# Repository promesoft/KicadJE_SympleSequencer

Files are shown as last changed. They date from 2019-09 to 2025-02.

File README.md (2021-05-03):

# KicadJE_SympleSequencer
Designed to fit the faceplate of a Hexinverter SympleSeq E2 faceplate from Re:Synthesis

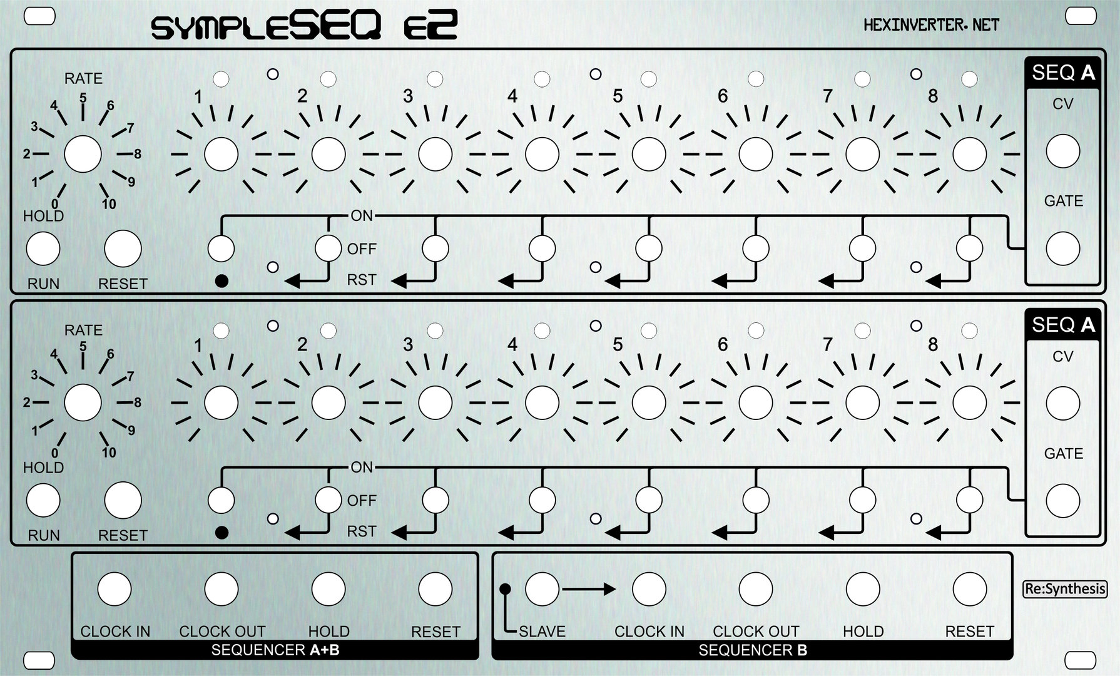
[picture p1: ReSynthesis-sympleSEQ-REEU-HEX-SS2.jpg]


# Purpose
1 - Match Hexinverter sch with Resynthesis panel

# Rev 2

# Status - Mouted - testing
## Initial 
| Stage  | Detail | Status |
| --- | --- | --- |
| create material  | sch/pcb | OK  |
| | gerber | OK |
| production  | | ok |
|  | produced | ok |
|  | delivered | ok |

## Preliminary validation
| Test  | Detail | Status |
| --- | --- | --- |
| Initial Inspection | clock board| ok |
| Initial Inspection | control board | ok  |
| Initial Technical Test |  | 100n capacitors in series w output is replaced w 2k |
| Initial Product Test |  | 100n C101 capacitor parallel w 150k |
| Initial Product Test |  | ongoing |

## Secondary validation
| Test  | Detail | Status |
| --- | --- |--- |
| Product Test | CV |  |
| Product Test | Gate | |
| Product Test | Clock internal |  |
| Product Test | Clock in |  |
| Product Test | Clock out |  |
| Product Test | Reset In/Button |  |
| Product Test | Hold In/Button |  |
| Quality | CV |  |
| Quality | Gate |  |
| Long Term Product Test |  | Good |
| Power Draw |  | 

## Errata
### Errata - clock
#### Series capacitors not working with reset (overloads CD4017)
 - replace w resistors (2k and 9k1 tested and working fine)
#### Hold not working 
 - Either swap R206 100k pullup with 22k-47k and R212 10k with 100k or tie hold to +12v works
### Errata - control
#### 

## Issues and Notes
### Clock
1 - diodes for hold input  
2 - diodes for reset input  
3 - Gate AND Clock for gate output to reset between gates - consider making a phase adjust for shorter/longer gates  
4 - OPEN resistor from Internal CLK to 4017 clock in (for use with Sequencer A that does not take slave clk input)
### Control
1 - switches still reversed  
2 - diode missing for reset  
3 - consider moving resistors from clk module to control as there is plenty of room  

# Schematics
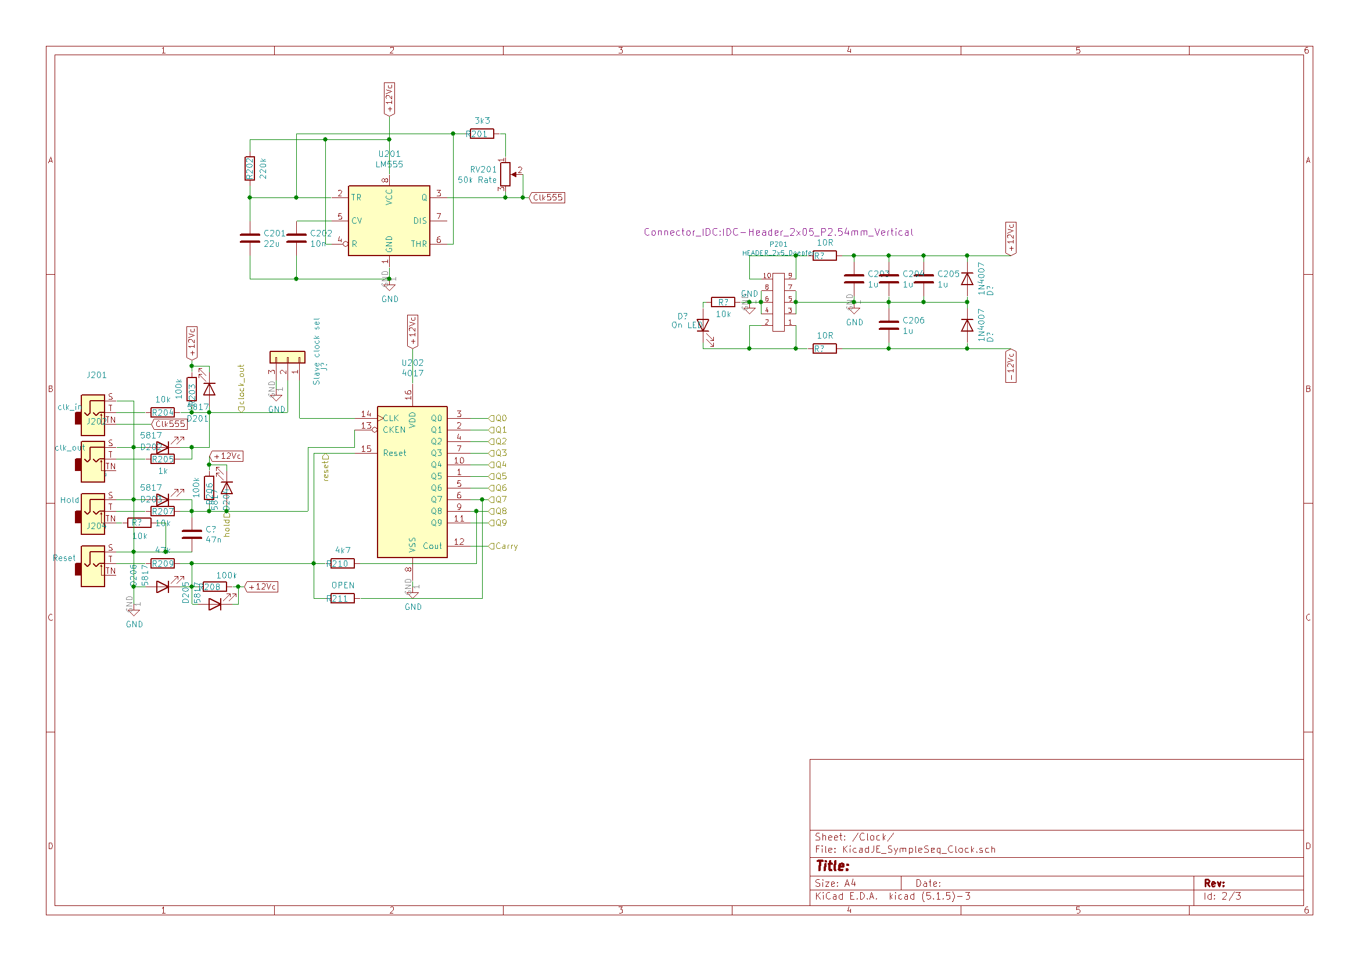
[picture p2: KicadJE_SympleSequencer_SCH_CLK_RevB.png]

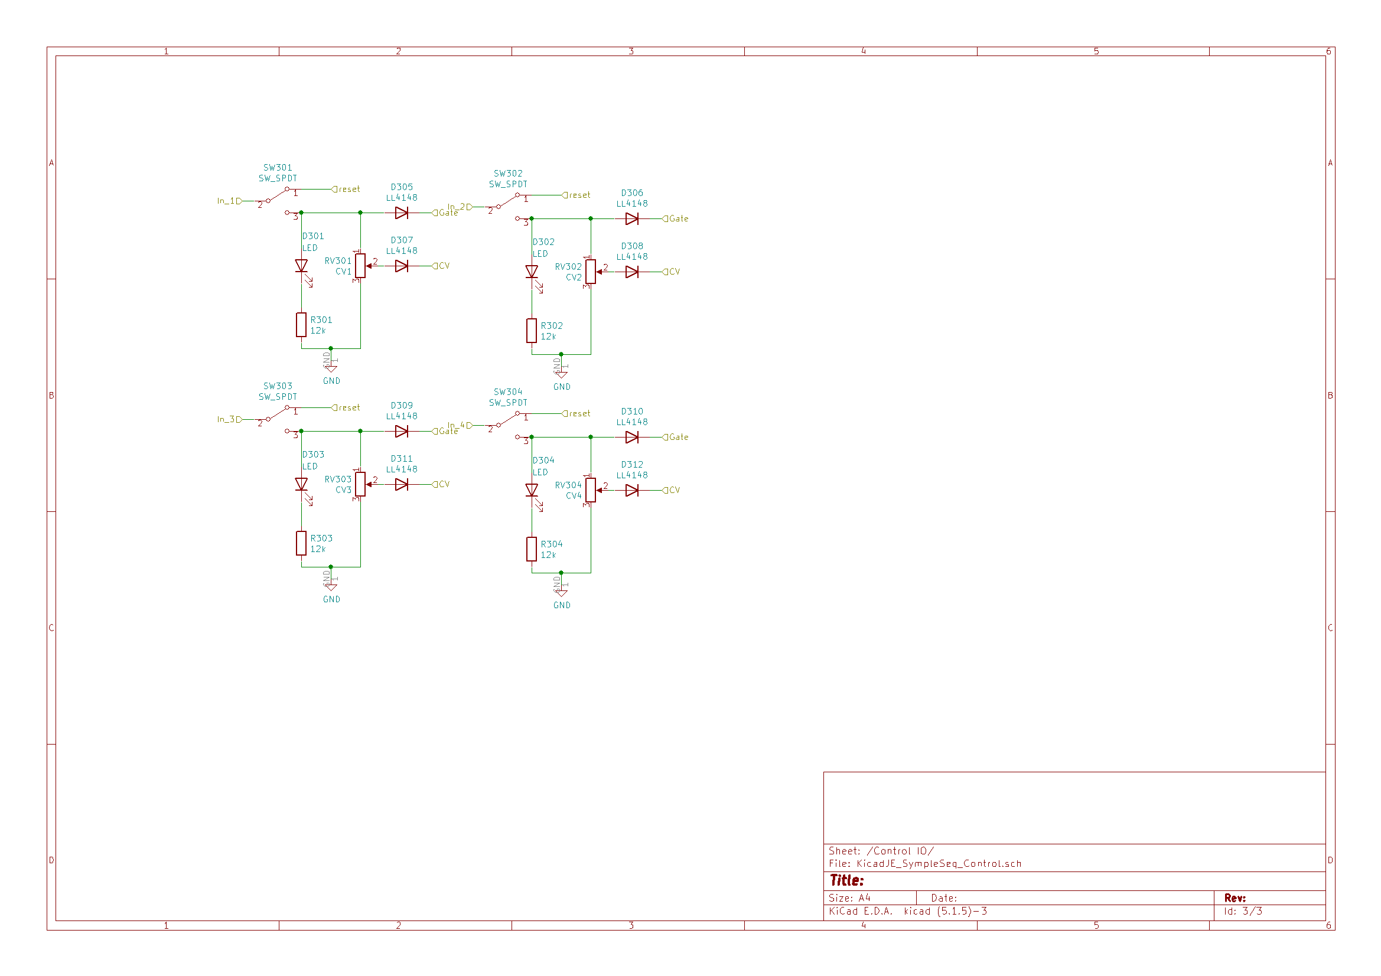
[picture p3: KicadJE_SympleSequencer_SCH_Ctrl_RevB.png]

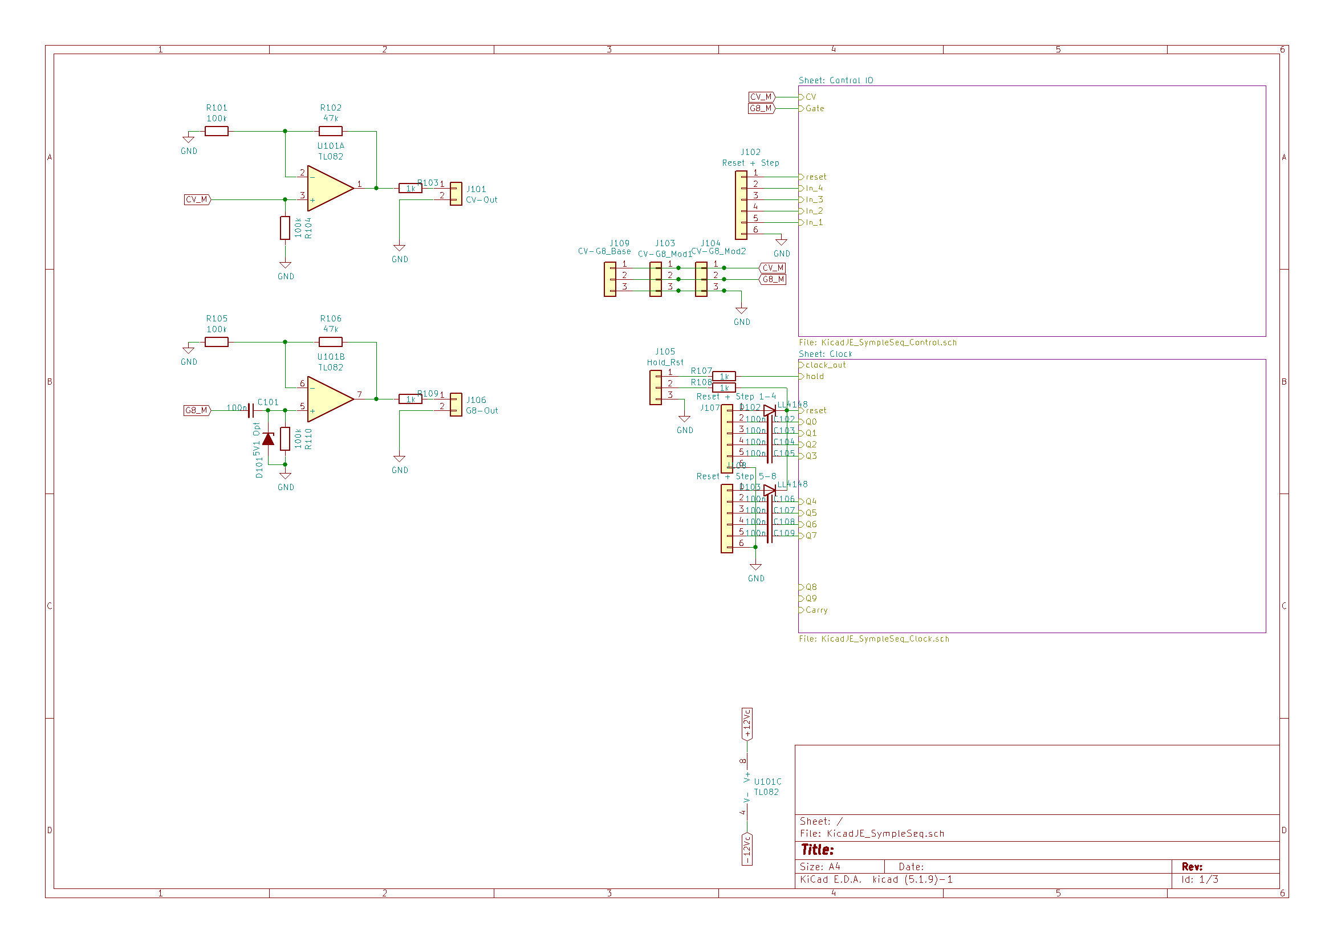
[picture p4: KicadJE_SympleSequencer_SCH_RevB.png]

# Pictures

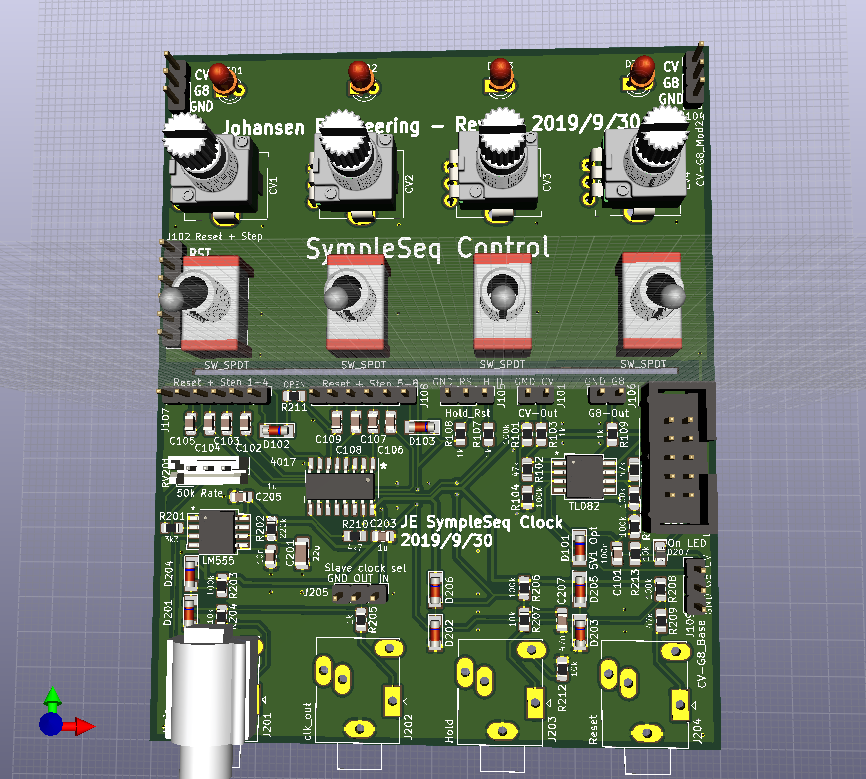
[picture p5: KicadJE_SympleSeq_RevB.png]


# Rev 1

# Status - Installed in rack - tweaking
## Initial 
| Stage  | Detail | Status |
| --- | --- | --- |
| create material  | sch/pcb | OK  |
| | gerber | OK |
| production  | | ok |
|  | produced | ok |
|  | delivered | ok |

## Preliminary validation
| Test  | Detail | Status |
| --- | --- | --- |
| Initial Inspection | clock board| ok - the jacks are 0,5-1mm too far away from the edge |
| Initial Inspection | control board | ok - see errata 3 |
| Initial Technical Test |  | ok |
| Initial Product Test |  | ok |

## Secondary validation
| Test  | Detail | Status |
| --- | --- |--- |
| Product Test | CV | ok |
| Product Test | Gate | See errata 4|
| Product Test | Clock internal | ok - a bit slow |
| Product Test | Clock in | ok |
| Product Test | Clock out | ok - could need a buffer |
| Product Test | Reset In/Button | ok |
| Product Test | Hold In/Button | ok - needs debounce |
| Quality | CV | Good |
| Quality | Gate | No good - needs shorter pulses |
| Long Term Product Test |  | Good |
| Power Draw |  | 

## Errata
### Errata - clock
#### 1 - Missing slave clk function (add diode or buffer - consider val of  R204 on master)
#### 4 - Gate signal becomes glide if two adjacent notes are on (never goes to 0V - consider AC couple)
#### 5 - Hold works - but can be a bit jumpy if clocked faster than clk
#### 7 - Hold button needs debounce (47nF?)

### Errata - control
#### 2 - D310 not connected to G8 output
#### 3 - Switches upside down (still works just opposite the faceplate signs)
#### 6 - Switches in reset works one at the time. Mutliselect becomes strange (diode missing)

## Issues and Notes
### Clock
1 - Missing silk on Jacks

2 - 
### Control

## Vital Components
 - CD4017
 - LM555
 - Jack connectors: PJ-324M (important for the footprint)
# Schematics
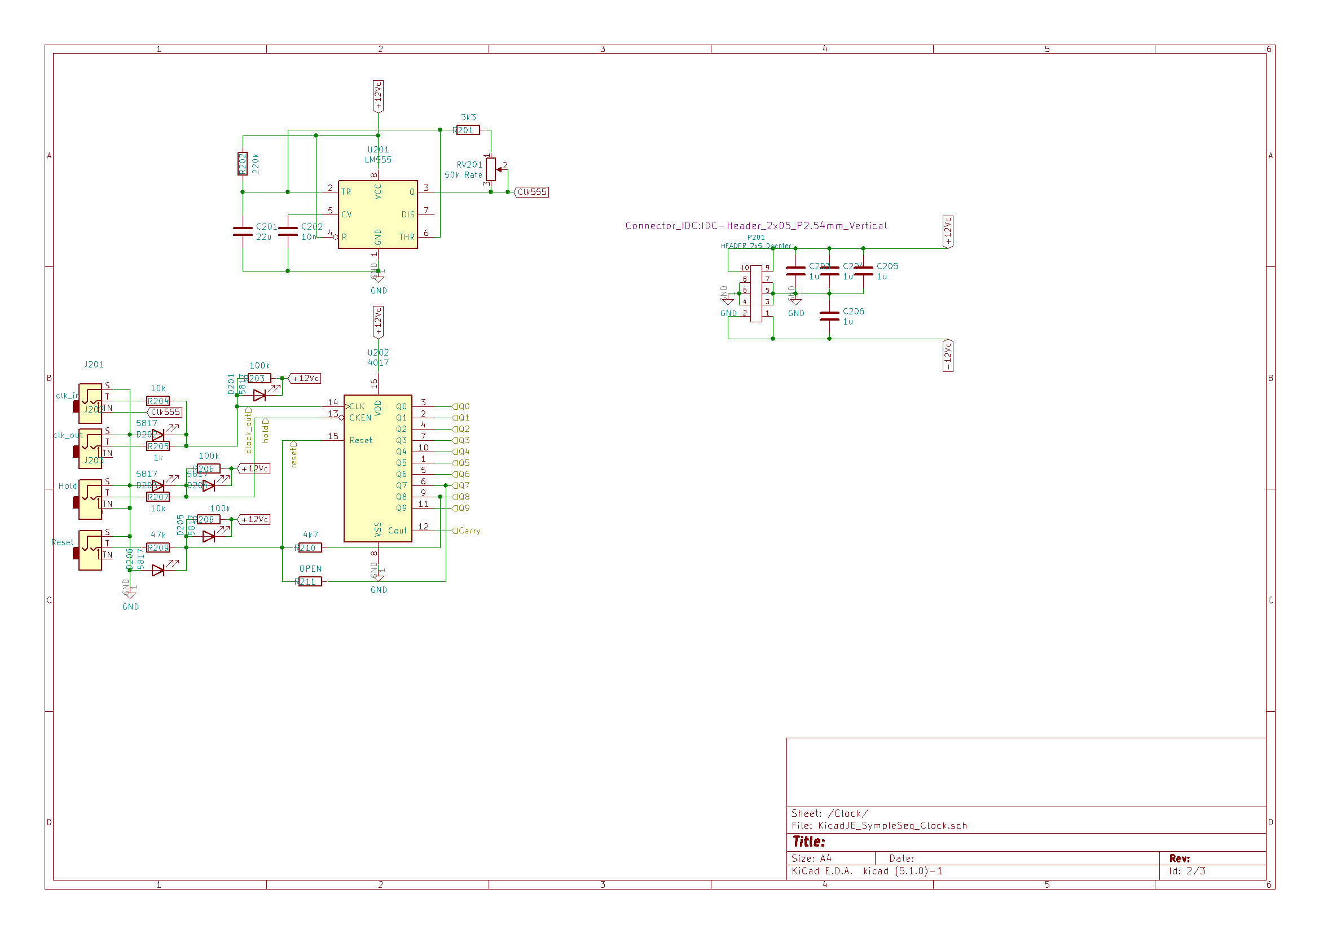
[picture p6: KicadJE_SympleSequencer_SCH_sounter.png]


# Pictures

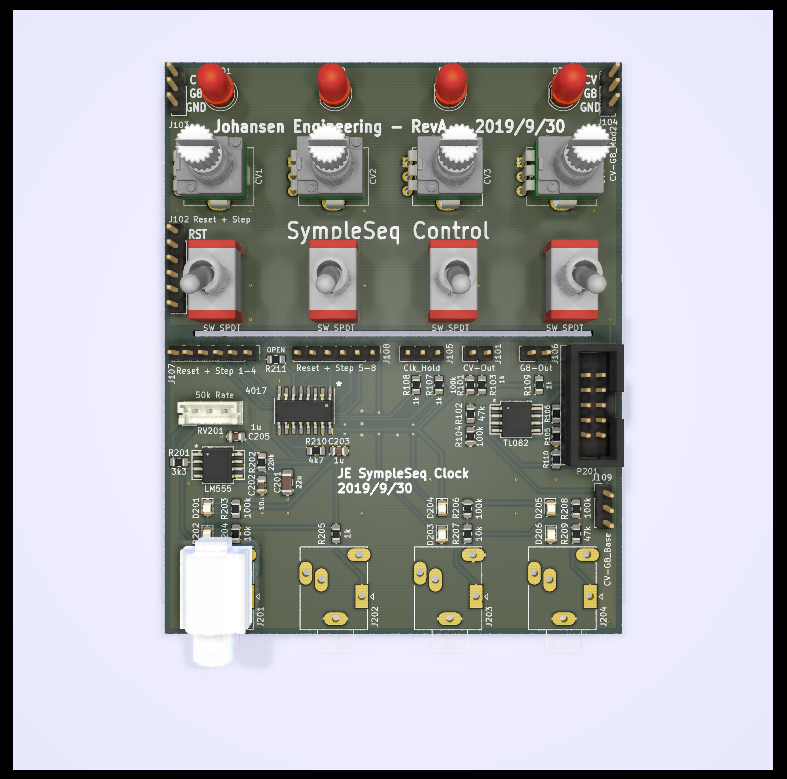
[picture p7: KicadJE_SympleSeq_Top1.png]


# Inspiration from 
Counter module in https://github.com/promesoft/KicadJE_EffectsUnit1

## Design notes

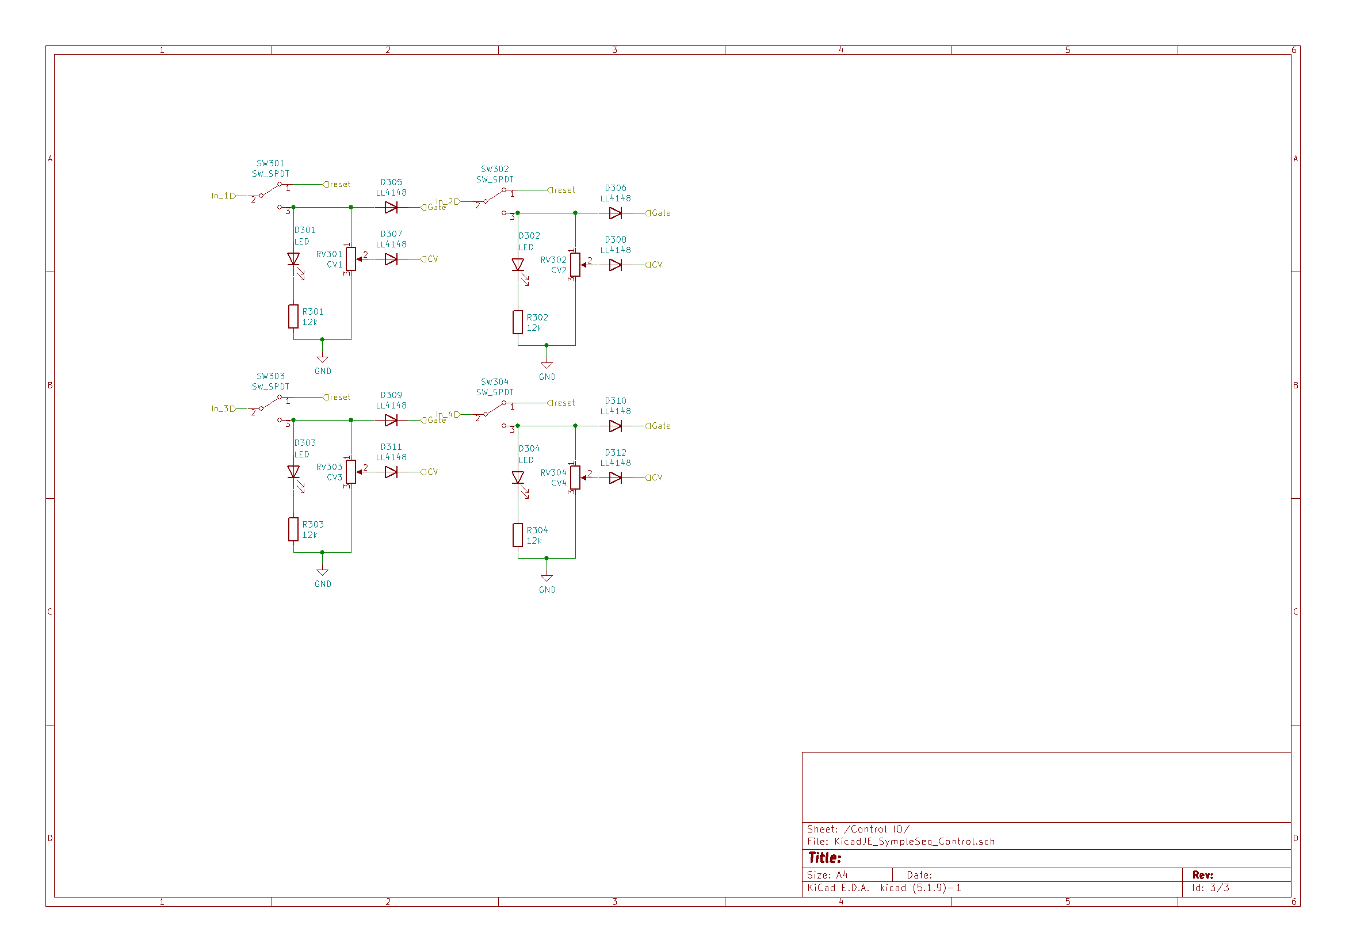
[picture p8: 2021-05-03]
KicadJE_SympleSequencer_SCH_Ctrl_RevA.png

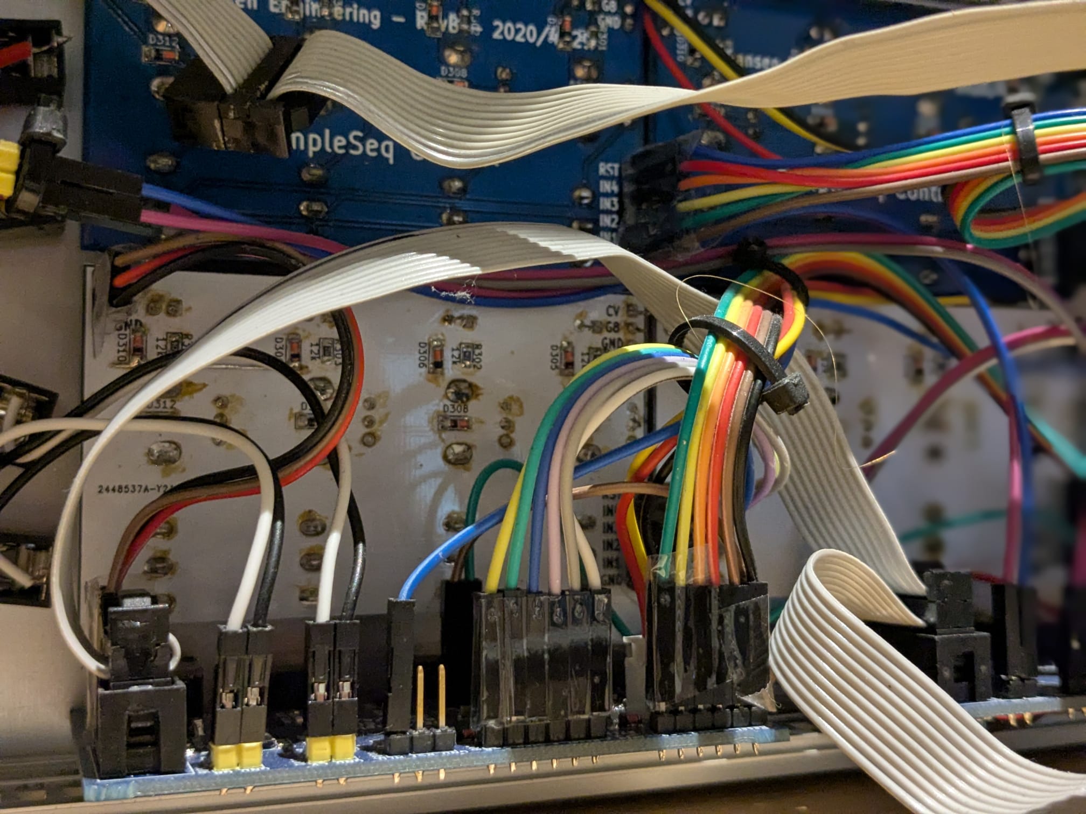
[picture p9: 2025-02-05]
SympleSeq_Back.jpg

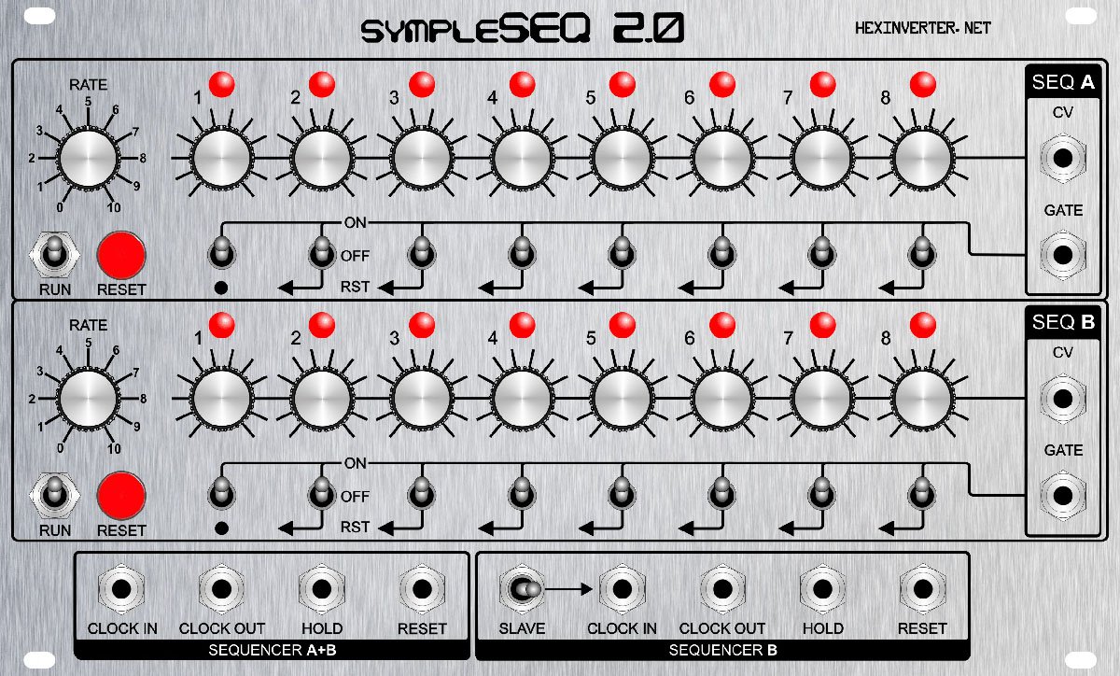
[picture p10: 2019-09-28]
RevA/SympleSeq.jpg

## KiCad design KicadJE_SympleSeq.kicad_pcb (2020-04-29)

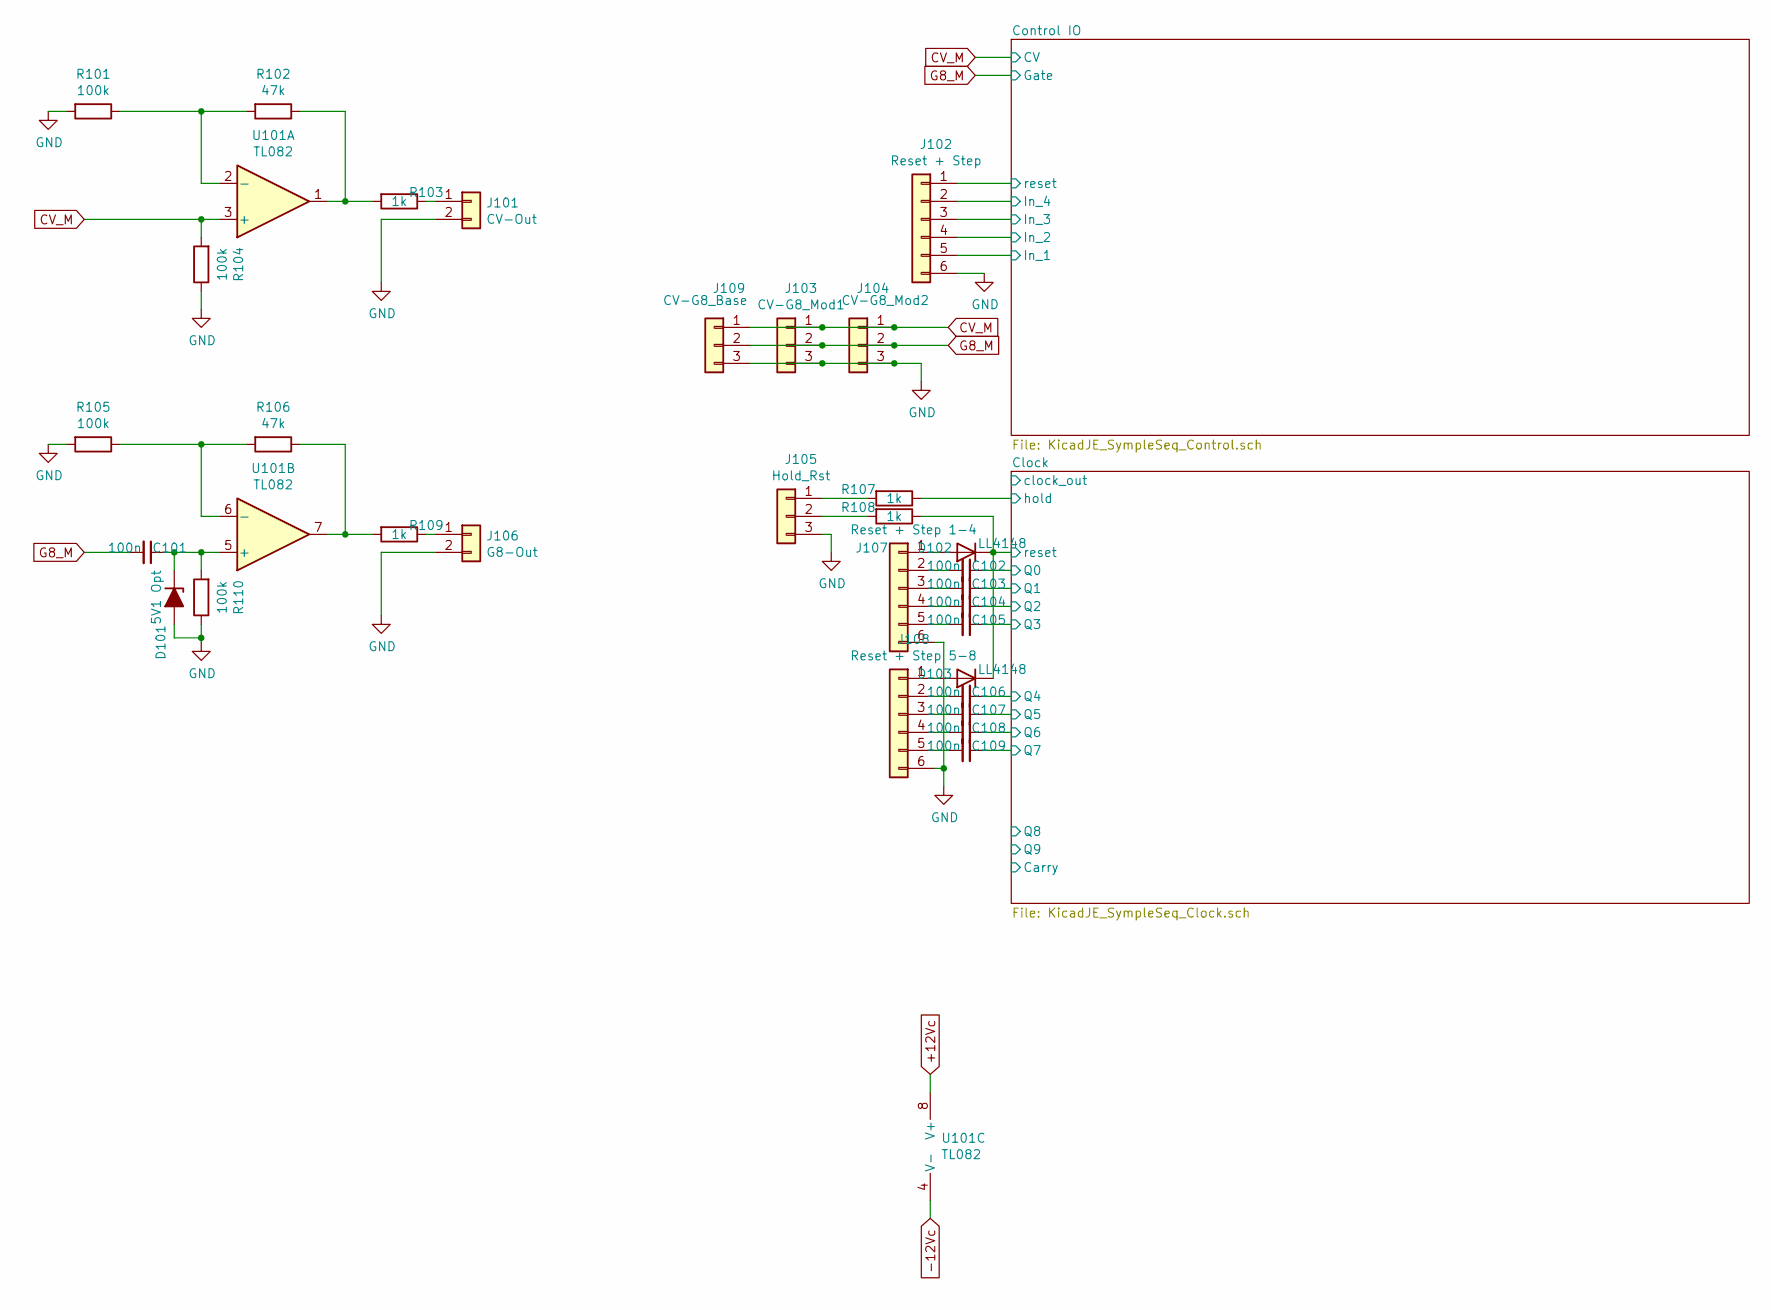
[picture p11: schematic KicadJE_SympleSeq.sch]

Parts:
C101, C102, C103, C104, C105, C106, C107, C108, C109: 100n; C_0805_AJ
D101: 5V1 Opt; D_MiniMELF
D102, D103: LL4148; D_MiniMELF
J101: CV-Out; PinHeader_1x02_P2.54mm_Vertical
J102: Reset + Step; PinHeader_1x06_P2.54mm_Vertical
J103: CV-G8_Mod1; PinHeader_1x03_P2.54mm_Vertical
J104: CV-G8_Mod2; PinHeader_1x03_P2.54mm_Vertical
J105: Hold_Rst; PinHeader_1x03_P2.54mm_Vertical
J106: G8-Out; PinHeader_1x02_P2.54mm_Vertical
J107: Reset + Step 1-4; PinHeader_1x06_P2.54mm_Vertical
J108: Reset + Step 5-8; PinHeader_1x06_P2.54mm_Vertical
J109: CV-G8_Base; PinHeader_1x03_P2.54mm_Vertical
R101, R104, R105, R110: 100k; R_0805_AJ
R102, R106: 47k; R_0805_AJ
R103, R107, R108, R109: 1k; R_0805_AJ
U101: TL082; AJ_SO-8_5.3x6.2mm_P1.27mm

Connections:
+12Vc: U101.8 (V+); also elsewhere on the board
-12Vc: U101.4 (V-); also elsewhere on the board
/Clock/Q0: C102.1; also elsewhere on the board
/Clock/Q1: C103.1; also elsewhere on the board
/Clock/Q2: C104.1; also elsewhere on the board
/Clock/Q3: C105.1; also elsewhere on the board
/Clock/Q4: C106.1; also elsewhere on the board
/Clock/Q5: C107.1; also elsewhere on the board
/Clock/Q6: C108.1; also elsewhere on the board
/Clock/Q7: C109.1; also elsewhere on the board
/Clock/hold: R107.1; also elsewhere on the board
/Clock/reset: D102.1 (K), D103.1 (K), R108.1; also elsewhere on the board
/Control IO/In_1: J102.5; also elsewhere on the board
/Control IO/In_2: J102.4; also elsewhere on the board
/Control IO/In_3: J102.3; also elsewhere on the board
/Control IO/In_4: J102.2; also elsewhere on the board
/Control IO/reset: J102.1; also elsewhere on the board
CV_M: J103.1, J104.1, J109.1, R104.2, U101.3 (+); also elsewhere on the board
G8_M: C101.2, J103.2, J104.2, J109.2; also elsewhere on the board
GND: D101.2 (A), J101.2, J102.6, J103.3, J104.3, J105.3, J106.2, J107.6, J108.6, J109.3, R101.2, R104.1, R105.2, R110.1; also elsewhere on the board
unnamed: C101.1, D101.1 (K), R110.2, U101.5 (+)
unnamed: C102.2, J107.2
unnamed: C103.2, J107.3
unnamed: C104.2, J107.4
unnamed: C105.2, J107.5
unnamed: C106.2, J108.2
unnamed: C107.2, J108.3
unnamed: C108.2, J108.4
unnamed: C109.2, J108.5
unnamed: D102.2 (A), J107.1
unnamed: D103.2 (A), J108.1
unnamed: J101.1, R103.1
unnamed: J105.1, R107.2
unnamed: J105.2, R108.2
unnamed: J106.1, R109.1
unnamed: R101.1, R102.2, U101.2 (-)
unnamed: R102.1, R103.2, U101.1
unnamed: R105.1, R106.2, U101.6 (-)
unnamed: R106.1, R109.2, U101.7

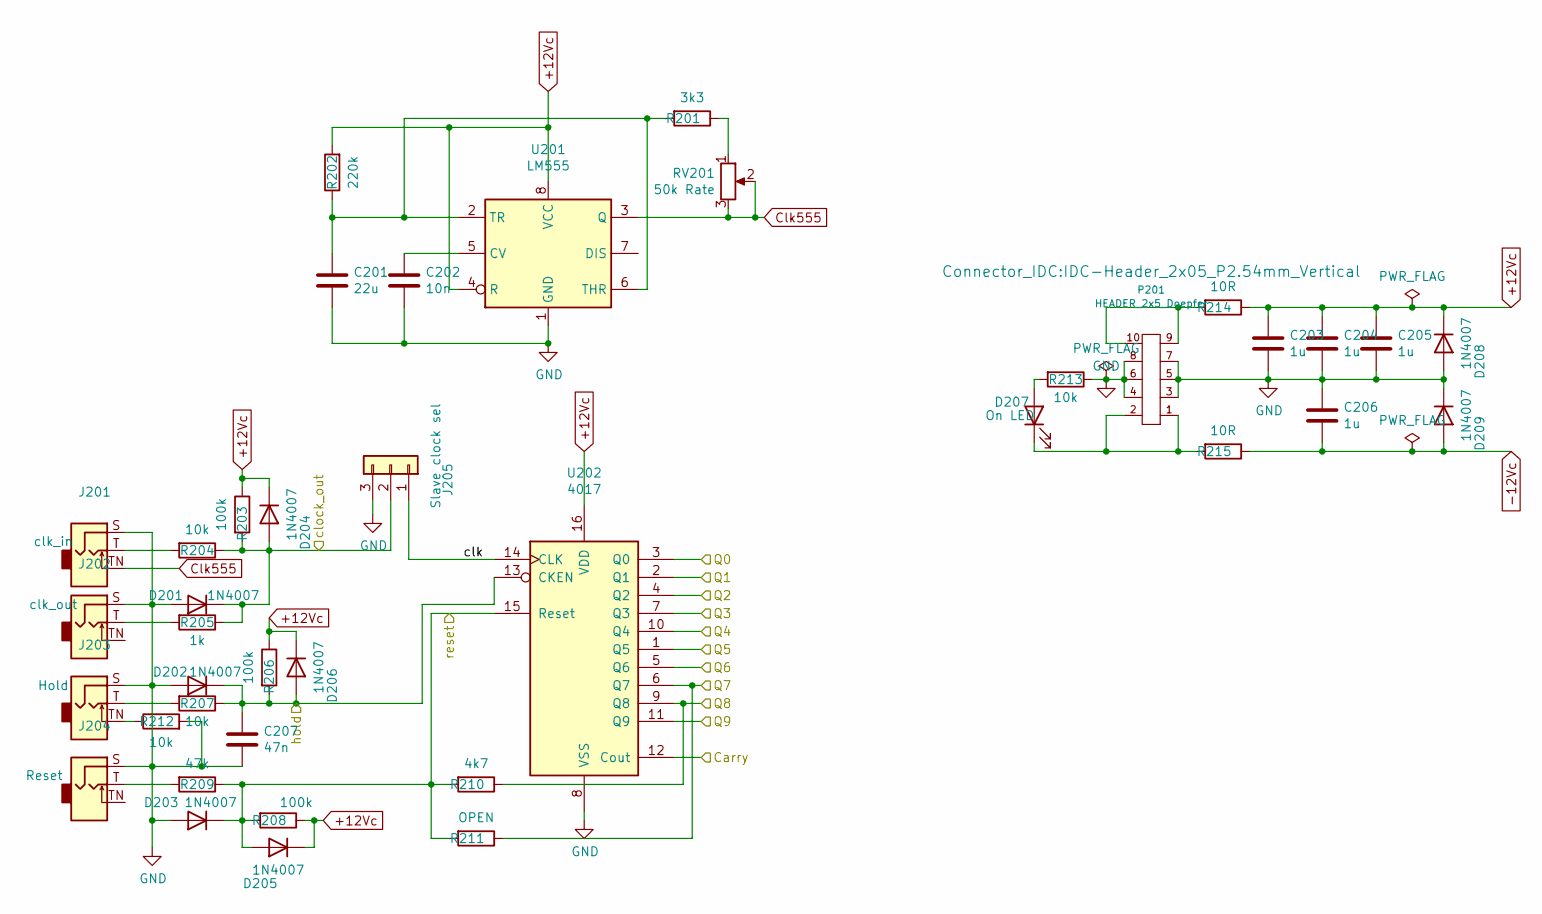
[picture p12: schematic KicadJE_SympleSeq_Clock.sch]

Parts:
C201: 22u; C_1206_3216Metric_Pad1.42x1.75mm_HandSolder
C202: 10n; C_0805_AJ
C203, C205: 1u; C_0805_AJ
C204, C206: 1u; C_1206_3216Metric_Pad1.42x1.75mm_HandSolder
C207: 47n; C_0805_AJ
D201, D202, D203, D204, D205, D206, D208, D209: 1N4007; D_MiniMELF
D207: On LED; D_0805_AJ
J201: clk_in; Jack_3.5mm_Ledino_KB3SPRS_Horizontal
J202: clk_out; Jack_3.5mm_Ledino_KB3SPRS_Horizontal
J203: Hold; Jack_3.5mm_Ledino_KB3SPRS_Horizontal
J204: Reset; Jack_3.5mm_Ledino_KB3SPRS_Horizontal
J205: Slave clock sel; PinHeader_1x03_P2.54mm_Vertical
P201: HEADER_2x5_Doepfer; IDC-Header_2x05_P2.54mm_Vertical
R201: 3k3; R_0805_AJ
R202: 220k; R_0805_AJ
R203, R206, R208: 100k; R_0805_AJ
R204, R207, R212, R213: 10k; R_0805_AJ
R205: 1k; R_0805_AJ
R209: 47k; R_0805_AJ
R210: 4k7; R_0805_AJ
R211: OPEN; R_0805_AJ
R214, R215: 10R; R_0805_AJ
RV201: 50k Rate; JST_EH_B3B-EH-A_1x03_P2.50mm_Vertical
U201: LM555; AJ_SO-8_5.3x6.2mm_P1.27mm
U202: 4017; SOIC-16_4.55x10.3mm_P1.27mm

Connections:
+12Vc: C203.1, C204.1, C205.1, D204.1 (K), D205.1 (K), D206.1 (K), D208.1 (K), R202.2, R203.1, R206.1, R208.1, R214.1, U201.4 (R), U201.8 (VCC), U202.16 (VDD); also elsewhere on the board
-12Vc: C206.2, D209.2 (A), R215.1; also elsewhere on the board
/Clock/Q0: U202.3 (Q0); also elsewhere on the board
/Clock/Q1: U202.2 (Q1); also elsewhere on the board
/Clock/Q2: U202.4 (Q2); also elsewhere on the board
/Clock/Q3: U202.7 (Q3); also elsewhere on the board
/Clock/Q4: U202.10 (Q4); also elsewhere on the board
/Clock/Q5: U202.1 (Q5); also elsewhere on the board
/Clock/Q6: U202.5 (Q6); also elsewhere on the board
/Clock/Q7: R211.1, U202.6 (Q7); also elsewhere on the board
/Clock/Q8: R210.1, U202.9 (Q8)
/Clock/clk: J205.1, U202.14 (CLK)
/Clock/clock_out: D201.1 (K), D204.2 (A), J205.2, R203.2, R204.1, R205.1
/Clock/hold: C207.1, D202.1 (K), D206.2 (A), R206.2, R207.1, U202.13 (CKEN); also elsewhere on the board
/Clock/reset: D203.1 (K), D205.2 (A), R208.2, R209.1, R210.2, R211.2, U202.15 (Reset); also elsewhere on the board
Clk555: J201.TN, RV201.2, RV201.3, U201.3 (Q)
GND: C201.2, C202.2, C203.2, C204.2, C205.2, C206.1, C207.2, D201.2 (A), D202.2 (A), D203.2 (A), D208.2 (A), D209.1 (K), J201.S, J202.S, J203.S, J204.S, J205.3, P201.3 (GND), P201.4 (GND), P201.5 (GND), P201.6 (GND), P201.7 (GND), P201.8 (GND), R212.2, R213.1, U201.1 (GND), U202.8 (VSS); also elsewhere on the board
unnamed: C201.1, R201.2, R202.1, U201.2 (TR), U201.6 (THR)
unnamed: C202.1, U201.5 (CV)
unnamed: D207.1 (K), P201.1 (-12), P201.2 (-12), R215.2
unnamed: D207.2 (A), R213.2
unnamed: J201.T, R204.2
unnamed: J202.T, R205.2
unnamed: J203.T, R207.2
unnamed: J203.TN, R212.1
unnamed: J204.T, R209.2
unnamed: P201.9 (+12), P201.10 (+12), R214.2
unnamed: R201.1, RV201.1

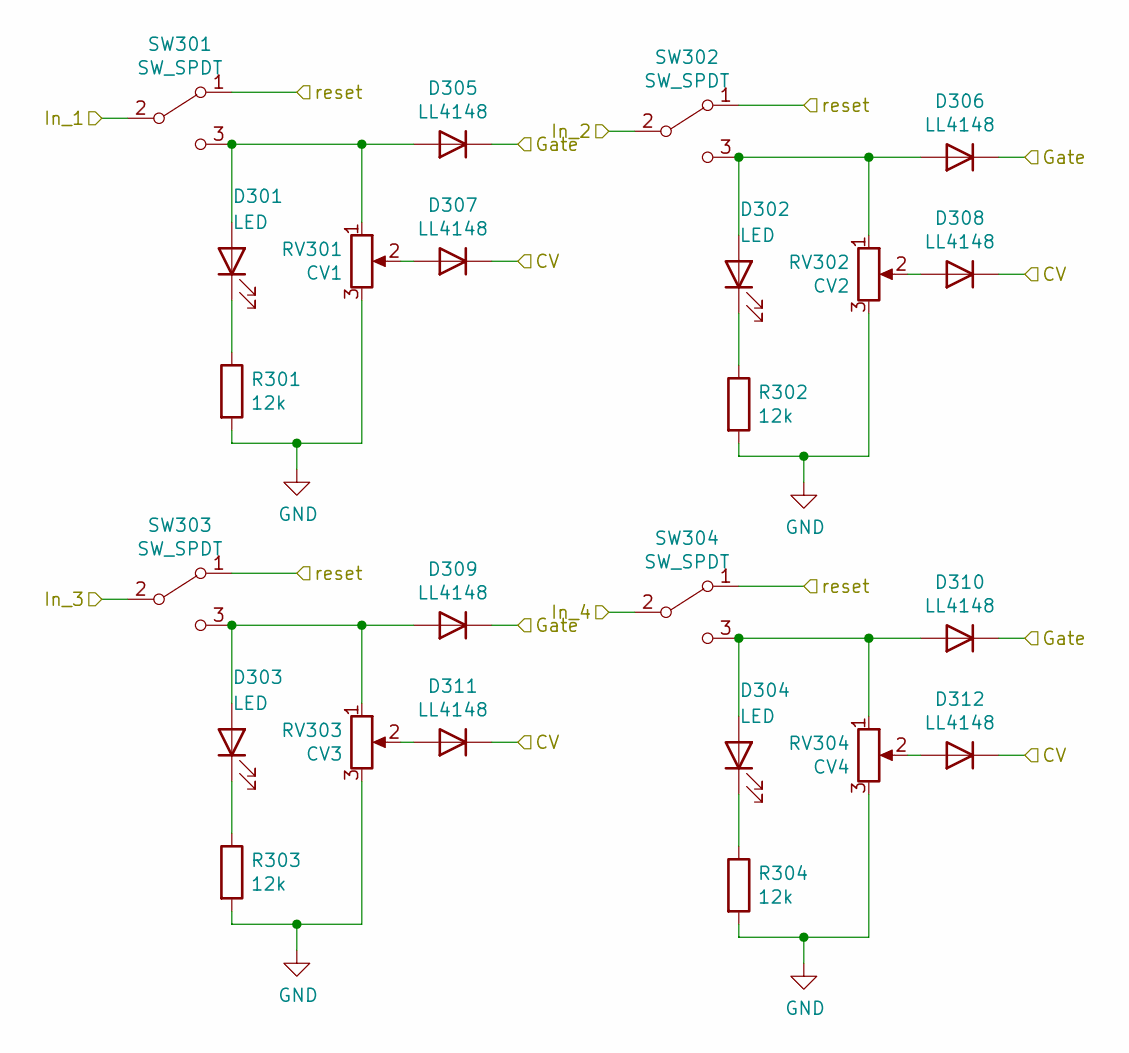
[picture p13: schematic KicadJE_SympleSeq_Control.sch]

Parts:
D301, D302, D303, D304: LED; LED_D3.0mm
D305, D306, D307, D308, D309, D310, D311, D312: LL4148; D_MiniMELF
R301, R302, R303, R304: 12k; R_0805_AJ
RV301: CV1; Potentiometer_China_RK09_Single_Vertical_AJ
RV302: CV2; Potentiometer_China_RK09_Single_Vertical_AJ
RV303: CV3; Potentiometer_China_RK09_Single_Vertical_AJ
RV304: CV4; Potentiometer_China_RK09_Single_Vertical_AJ
SW301, SW302, SW303, SW304: SW_SPDT; SP1MS1

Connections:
/Control IO/In_1: SW301.2 (B); also elsewhere on the board
/Control IO/In_2: SW302.2 (B); also elsewhere on the board
/Control IO/In_3: SW303.2 (B); also elsewhere on the board
/Control IO/In_4: SW304.2 (B); also elsewhere on the board
/Control IO/reset: SW301.1 (A), SW302.1 (A), SW303.1 (A), SW304.1 (A); also elsewhere on the board
CV_M: D307.1 (K), D308.1 (K), D311.1 (K), D312.1 (K); also elsewhere on the board
G8_M: D305.1 (K), D306.1 (K), D309.1 (K), D310.1 (K); also elsewhere on the board
GND: R301.2, R302.2, R303.2, R304.2, RV301.3, RV302.3, RV303.3, RV304.3; also elsewhere on the board
unnamed: D301.1 (K), R301.1
unnamed: D301.2 (A), D305.2 (A), RV301.1, SW301.3 (C)
unnamed: D302.1 (K), R302.1
unnamed: D302.2 (A), D306.2 (A), RV302.1, SW302.3 (C)
unnamed: D303.1 (K), R303.1
unnamed: D303.2 (A), D309.2 (A), RV303.1, SW303.3 (C)
unnamed: D304.1 (K), R304.1
unnamed: D304.2 (A), D310.2 (A), RV304.1, SW304.3 (C)
unnamed: D307.2 (A), RV301.2
unnamed: D308.2 (A), RV302.2
unnamed: D311.2 (A), RV303.2
unnamed: D312.2 (A), RV304.2

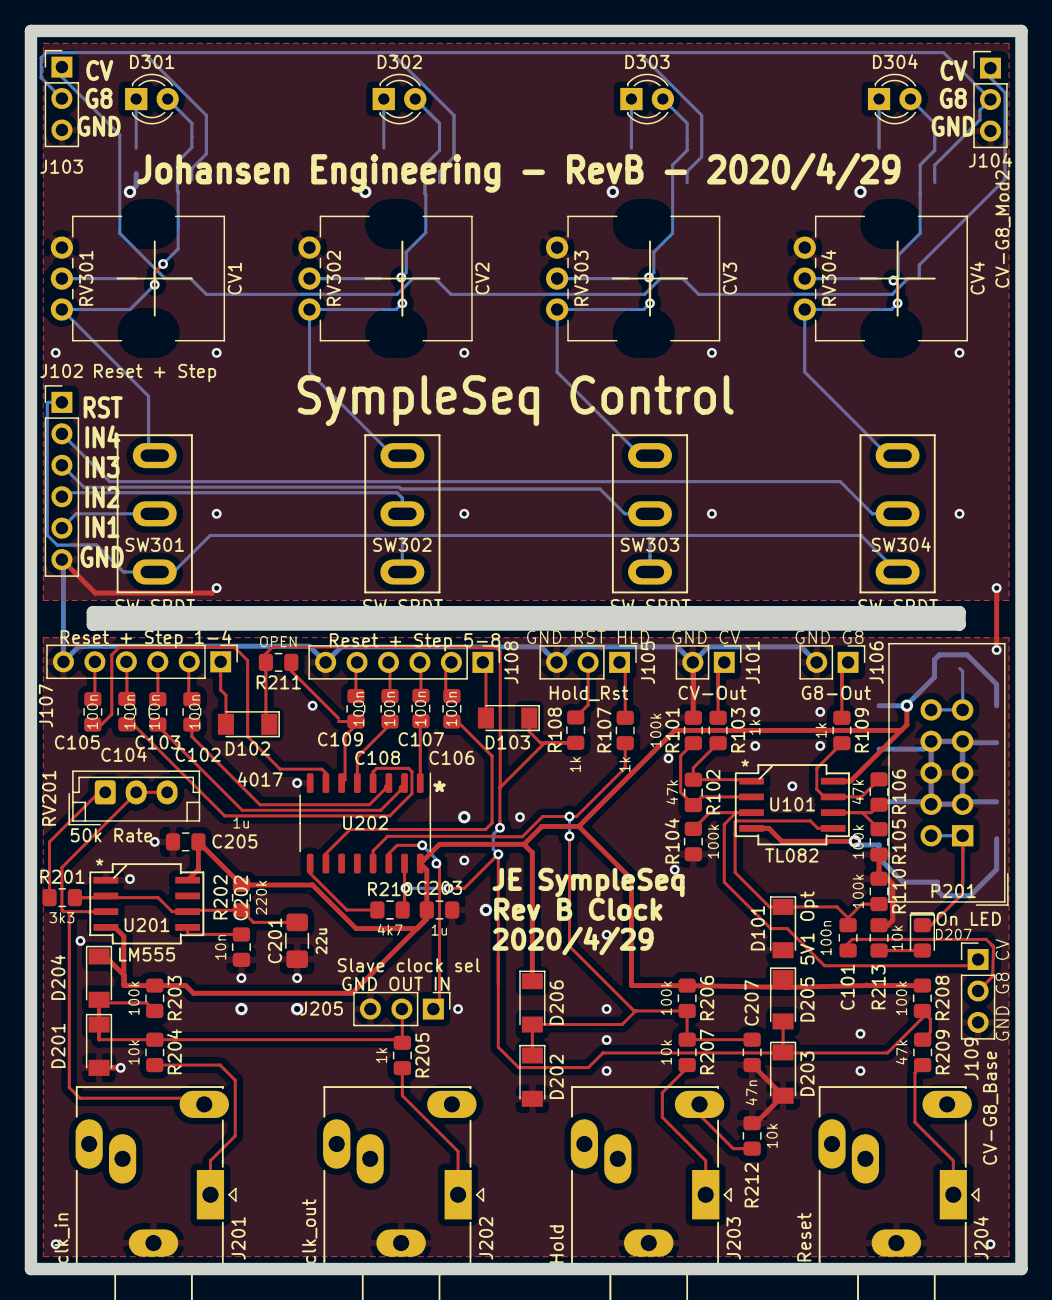
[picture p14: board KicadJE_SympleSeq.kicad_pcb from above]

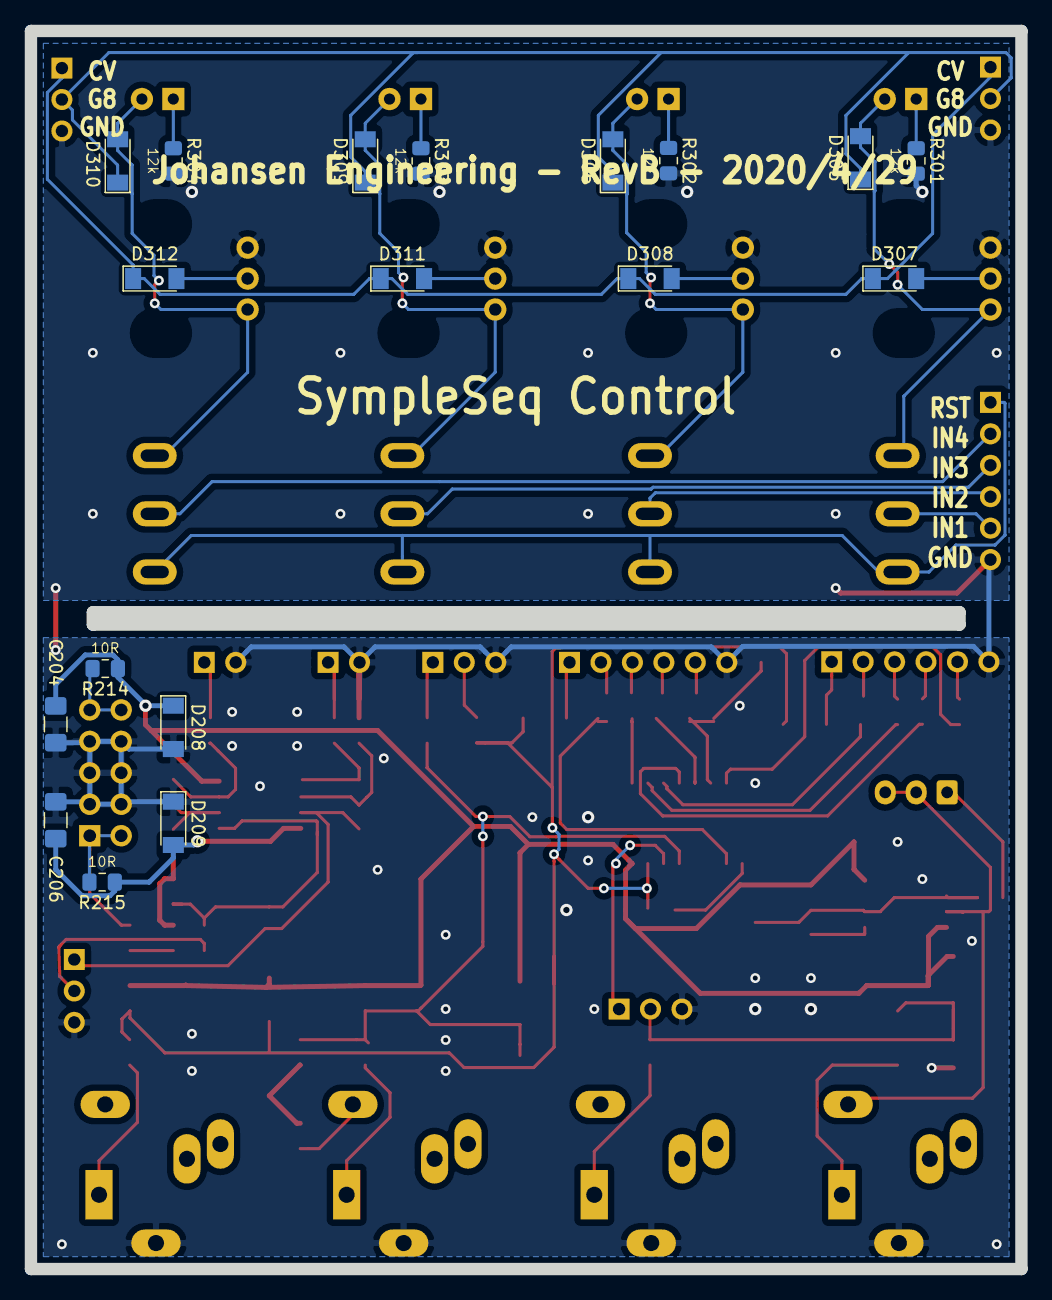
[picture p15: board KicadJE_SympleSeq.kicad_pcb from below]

Board: 2 copper layers, 80.0 x 100.0 mm, 96 parts (18 on the bottom side), 66 nets.

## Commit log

2019-09-29 Counter w protection
    [KicadJE_SympleSeq.sch, KicadJE_SympleSeq_Clock.sch]
2019-09-29 555 done sch
    [KicadJE_SympleSeq_Clock.sch]
2019-09-29 Hierarchical pins
    [KicadJE_SympleSeq.sch]
2019-09-29 Sch taking form
    [KicadJE_SympleSeq.sch, _saved_KicadJE_SympleSeq.sch]
2019-09-29 pin headers
    [KicadJE_SympleSeq.sch, _saved_KicadJE_SympleSeq.sch]
2019-09-30 base circuit done
    [KicadJE_SympleSeq.sch, KicadJE_SympleSeq_Clock.sch]
2019-09-30 Annotate #1
    [KicadJE_SympleSeq.sch, KicadJE_SympleSeq_Clock.sch, KicadJE_SympleSeq_Control.sch]
2019-09-30 control module PCB init
    [KicadJE_SympleSeq.kicad_pcb, KicadJE_SympleSeq.sch, KicadJE_SympleSeq_Clock.sch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]
2019-09-30 Control Done PCB
    [KicadJE_SympleSeq.kicad_pcb]
2019-09-30 Init Clock board
    [KicadJE_SympleSeq.sch, KicadJE_SympleSeq_Clock.sch]
2019-09-30 clock board done
    [KicadJE_SympleSeq.kicad_pcb, KicadJE_SympleSeq.sch, KicadJE_SympleSeq_Clock.sch]
2019-12-11 Update KicadJE_SympleSeq.kicad_pcb-bak
2020-04-27 RevA -> RevB
    [KicadJE_SympleSeq.kicad_pcb, KicadJE_SympleSeq.sch, KicadJE_SympleSeq_Clock.sch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]
2020-04-27 slave clk - debounce hold etc
    [KicadJE_SympleSeq.sch, KicadJE_SympleSeq_Clock.sch]
2020-04-27 RevB updates
    [KicadJE_SympleSeq.sch]
2020-04-29 Diode prot from LED->1N4007
    [KicadJE_SympleSeq_Clock.sch]
2020-04-29 ERC Rev B
    [KicadJE_SympleSeq.sch, KicadJE_SympleSeq_Clock.sch]
2020-04-29 AJ Footprints
    [KicadJE_SympleSeq.sch, KicadJE_SympleSeq_Clock.sch, KicadJE_SympleSeq_Control.sch]
2020-04-29 AJ footprints updated
    [KicadJE_SympleSeq.sch, KicadJE_SympleSeq_Clock.sch, KicadJE_SympleSeq_Control.sch]
2020-04-29 D310 connected
    [KicadJE_SympleSeq.kicad_pcb]
2020-04-29 Updated PCB rev B
    [KicadJE_SympleSeq.kicad_pcb]
2020-04-29 Update KicadJE_SympleSeq_Control.sch
    Fix LED error 0805 -> LED_THT:LED_D3.0mm
    [KicadJE_SympleSeq_Control.sch]
2020-04-29 PCB rdy for DRC
    [KicadJE_SympleSeq.kicad_pcb]
2020-04-29 Fix 3mm LED
    [KicadJE_SympleSeq.kicad_pcb]
2020-04-29 Unconnected fix
    [KicadJE_SympleSeq.kicad_pcb]
2020-04-29 move BOM to rev A
2020-04-29 RevB Gerber
    [KicadJE_SympleSeq-B_Cu.gbr, KicadJE_SympleSeq-B_Mask.gbr, KicadJE_SympleSeq-B_Paste.gbr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]
2020-04-29 Fix few things for RevB (2)
    [KicadJE_SympleSeq.kicad_pcb]
2020-04-29 RevB2
    fix Jack a bit further to the front
    labeling
    Minor adj to fix courtyard overlaps
    [KicadJE_SympleSeq-B_Cu.gbr, KicadJE_SympleSeq-B_Mask.gbr, KicadJE_SympleSeq-B_Paste.gbr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]
2021-05-03 pict etc
    [KicadJE_SympleSeq.sch, KicadJE_SympleSeq_Clock.sch, KicadJE_SympleSeq_Control.sch]
